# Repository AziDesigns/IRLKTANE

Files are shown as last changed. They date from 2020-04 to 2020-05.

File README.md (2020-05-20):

# IRLKTANE
A real life (but not really real) version of the game Keep Talking and Nobody Explodes
Built for - Arduino

Inspired by one of my favorite games (KTaNE) and the realization that this could be made into a physical version after seeing a reddit post by u/advicevice of the "maze" module I decided I had to build it myself.

The goal is not to make hot swappable modules but rather 1 of each module that works. 
Some modules are obviously not as realistic (ex. wire sequences) if I want it to be EXACTLY like the game but I am willing to make small adjustments to make it follow the same original game rules. 

*I do not plan to make any moded modules at this time but may in the future if all other modules are completed and optimized.*

The game is played with a minimum of 2 players, with one player as the "Defuser" and the remaining player(s) as the "Experts" reading the official bomb defusal manual from KTaNE VERSION 1 - VERIFICATION CODE #241 ONLY. I am not going to cover all game rules here, just go look at the manual on their site.

Currently it is being built with fixed variables but the goal will be once all modules are working as intended, you can create/ customize the difficulty by turning specific modules on/off as well as adjusting things like # of strikes (3 by default) or starting time (7 minutes by default).
*Fixed Variables include things like ports, batteries, & lit indicators.*

There will NOT be any 3d models released as I plan to make this out of wood, sheet metal, and plexiglass cutouts to hide/show the batteries, ports, etc.

#### Table of Contents
1. Getting Started w/ Software
- 1.1. Needed Libraries/ Files
- 1.2. Installation
2. Components
3. Modules
4. Built With
5. Authors
6. Credits

#### 1. Getting Started
These instructions will get you a copy of the project up and running.

#### 1.1 Prerequisites
In order for the code to work, you will need the following libraries:

- SevenSegmentTM1637 - [link](https://github.com/bremme/arduino-tm1637) 
- LedControl - [link](https://github.com/wayoda/LedControl)
- [REMOVED / NO LONGER NEEDED]~~LiquidCrystal~~ - [link](https://www.arduinolibraries.info/libraries/liquid-crystal)
- LiquidCrystal_I2C - [link](https://www.arduinolibraries.info/libraries/liquid-crystal-i2-c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)
- The files in this repository

#### 1.2 Installation
    1 - Download the .zip files for the libraries
    2 - Open Arduino IDE
    3 - Click Sketch -> Include Library -> Add .ZIP Library
    4 - Select the library zip file you downloaded
    5 - Repeat steps 3 and 4 for each library
    6 - Download the files in this repository and put all of them in the Arduino folder (sub-folder name must match .ino file name)

A Fritzing scheme has been added to this repository with instructions to build the circuit. It is a *WIP*, and as each module gets tested I will continue to update the pin mapping. (For example, right now each LED goes directly to the arduino, in the future they will all be run from a MAX7219 to reduce pin usage)

Next, connect the Arduino board to your computer and load the program to the board.

#### 2. Components (List Subject to Change) - will be updated upon completion of final build as it continues to change.
    1 - Arduino MEGA 2560 R3
    2 - Neopixel Stick
    1 - Red 7-segment clock display
    3 - 7 Segment Display (2-Digit)
    1 - Adafruit NeoPixel NeoMatrix 8x8 - 64 RGB LED Pixel Matrix
    4 - MAX7219 (DRIVES DISPLAYS AND LED MATRIX)
    1 - CUSTOM LED Matrix PCB or Make your own DIY on perfboard
    27 - Green LED
    2 - Yellow LED
    1 - 7 Segment Display (Single Digit)
    2 - 7 Segment Display - 20mm (4 Digit)
    1 - Red Square LED Button
    1 - Blue Square LED Button
    1 - Yellow Square LED Button
    1 - Green Square LED Button
    1 - 5-way Navigation switch
    1 - Snap-Action Standard Micro Switch with Lever
    30 - Mini Pushbutton Switch
    1 - RGB Button
    3 - LCD Display 16x2 I2C
    1 - LCD Display 20x4 I2C
    1 - large fake capacitor //for the needy module aesthetics
    Many Resistors, Capacitors, and Jumpers

#### 3. Modules

| Module Type  | Module Name | Sketched | Coded | Made |
| --- | --- |:---:|:---:|:---:|
| Normal | Button |:heavy_check_mark:|:heavy_check_mark:|:heavy_check_mark:|
| Needy | Capacitor Discharge |:heavy_check_mark:|:heavy_check_mark:|:heavy_check_mark:|
| Needy | Knob |:heavy_check_mark:|:heavy_check_mark:|:heavy_check_mark:|
| Normal | Maze |:heavy_check_mark:|:heavy_check_mark:|:heavy_check_mark:|
| Normal | Memory |:heavy_check_mark:|:heavy_check_mark:| |
| Normal | Morse |:heavy_check_mark:|:heavy_check_mark:|:heavy_check_mark:|
| Normal | Password |:heavy_check_mark:|:heavy_check_mark:| |
| Normal | Simon Says |:heavy_check_mark:|:heavy_check_mark:|:heavy_check_mark:|
| Needy | Venting Gas |:heavy_check_mark:| | |
| Normal | Who's On First |:heavy_check_mark:|:heavy_check_mark:|:heavy_check_mark:|
| Widget | Buzzer |:heavy_check_mark:|:heavy_check_mark:|:heavy_check_mark:|
| Widget | Timer |:heavy_check_mark:|:heavy_check_mark:|:heavy_check_mark:|
| Widget | Strikes |:heavy_check_mark:|:heavy_check_mark:|:heavy_check_mark:|
| Widget | Batteries |:heavy_check_mark:| | |
| Widget | Indicators |:heavy_check_mark:| | |
| Widget | Ports |:heavy_check_mark:| | |
| Normal | Complicated Wires | | | |
| Normal | Keypad (Symbols) | | | |
| Normal | Wire Sequence | | | |
| Normal | Wires | | | |

#### 4. Built With
[Arduino](https://www.arduino.cc/en/main/software) - The IDE used to code the modules logic.

[Fritzing](http://fritzing.org/home/) - The program used to create the components layout and wiring diagram.

#### 5. Authors
AziAssassin

#### 6. Credits
Thanks to calingeorgeadrian && ema1ih for setting the ground work for me to learn and get the basics of how they wrote their version of a select few of these modules.

Thanks to reddit u/advicevice for making me realize the potential this idea had to become a phyical game.

Last but not least: Keep Talking and Nobody Explodes - the [game](https://keeptalkinggame.com/) that inspired me in the first place.

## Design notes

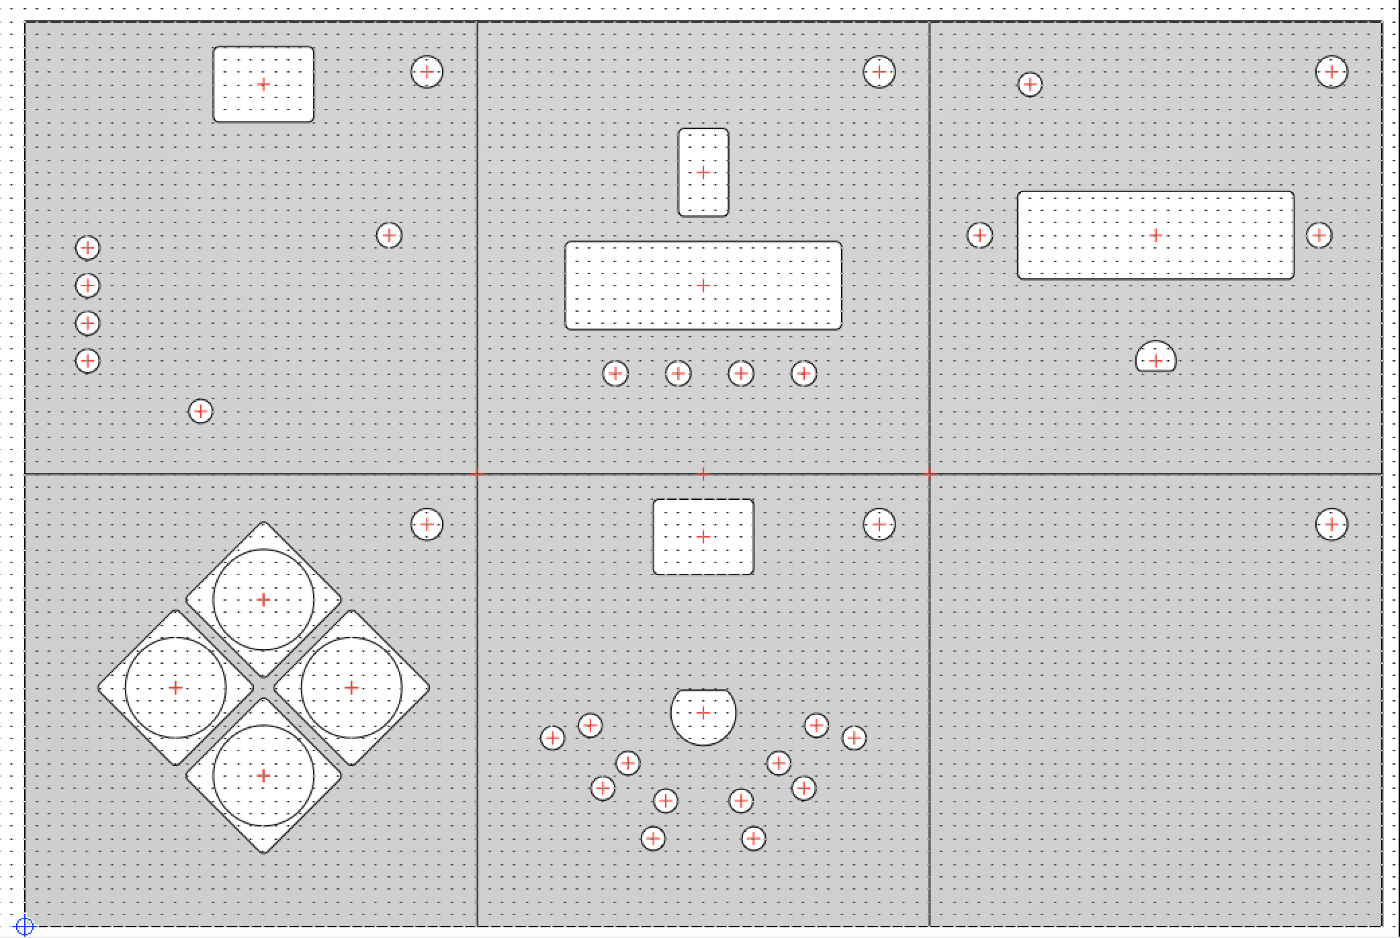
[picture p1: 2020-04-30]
PanelDesigns/rearPanelImageV1.png

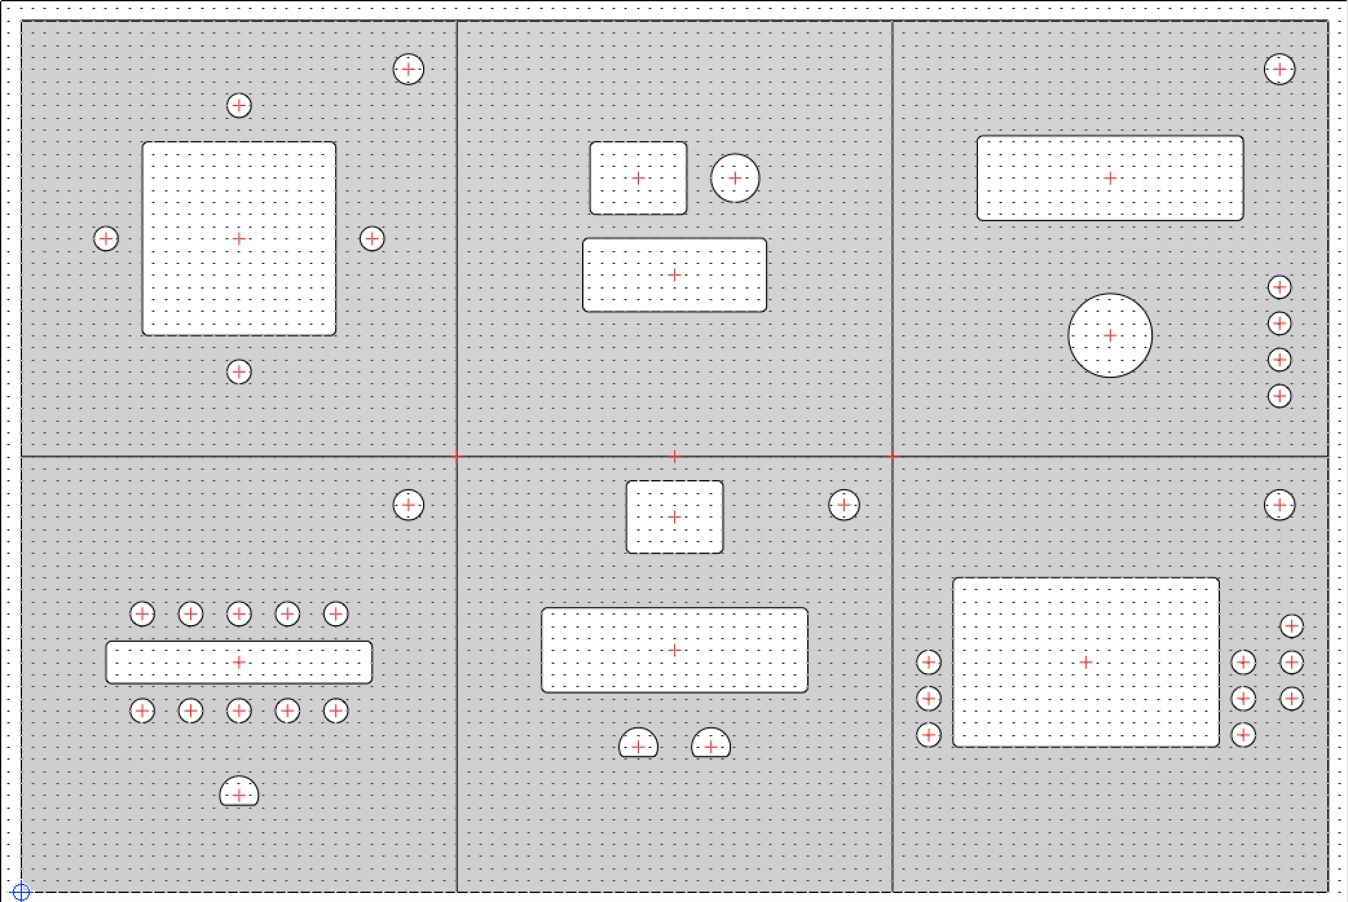
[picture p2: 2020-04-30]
PanelDesigns/frontPanelImagev1.png

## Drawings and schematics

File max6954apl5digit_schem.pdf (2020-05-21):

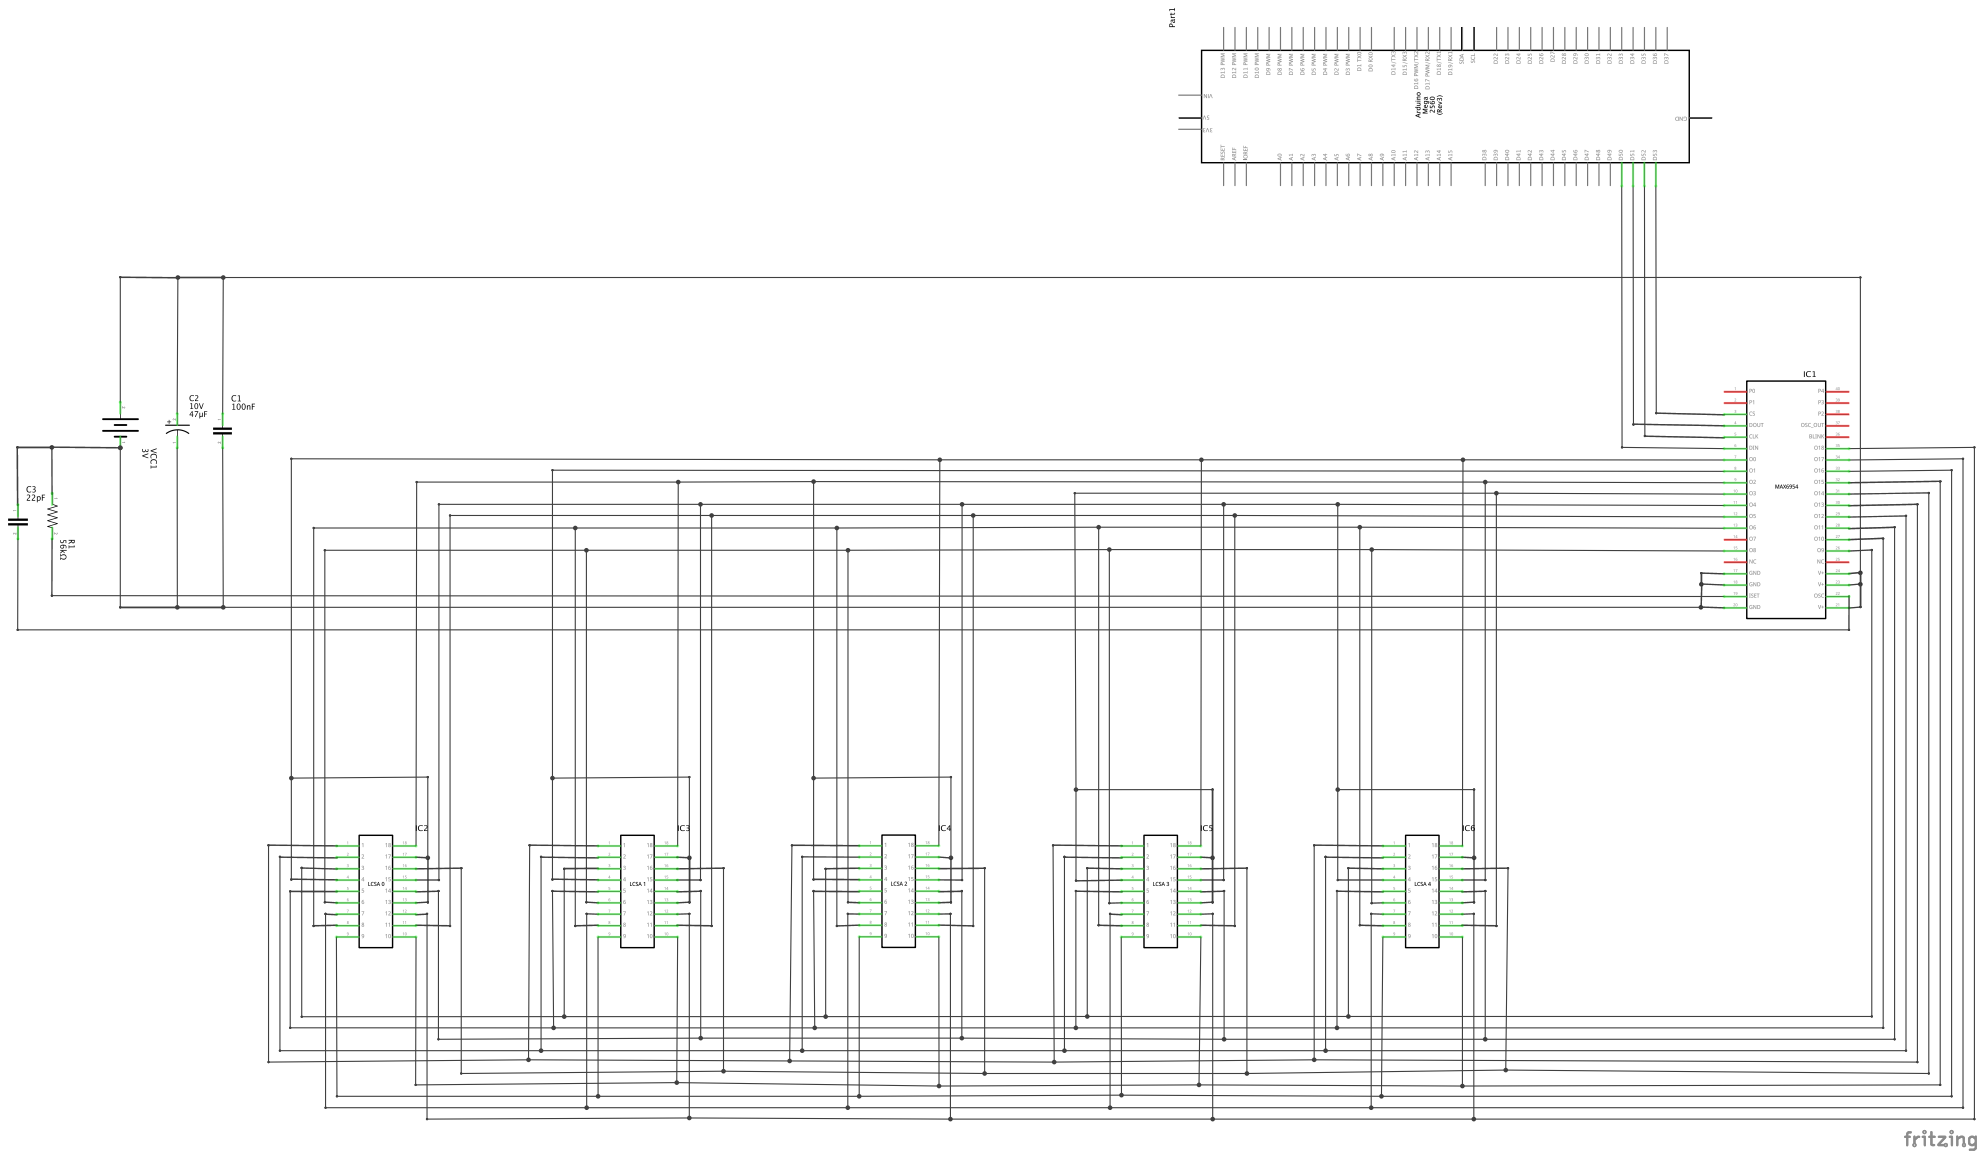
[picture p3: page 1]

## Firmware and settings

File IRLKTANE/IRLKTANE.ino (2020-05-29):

//THIS BOMB USES KTANE BOMB DEFUSAL MANUAL VERSION 1 VERIFICATION CODE #241 ONLY
/*
  KNOWN ISSUES:
  Module lights are staying on after bomb is defused. Only lights that should stay on are module complete green leds
*/
#include <LiquidCrystal_I2C.h>
#include <LedControl.h>
#include <SevenSegmentExtended.h>

#define BOMB_TIMER_MINUTES 7 // total bomb starting time min
#define BOMB_TIMER_SECONDS 0 // total bomb starting time sec

/*  LEVEL 0 = MINIMAL SERIAL PRINT
    LEVEL 1 = PER USER ACTION LOGGING & BOMB VALUES
    LEVEL 2 = PER FUNCTION CALL LOGGING
    LEVEL 3 = SAME AS L3 WITH loop, setup, morseDisplay, displayTime, and mazeOne FUNCTIONS INCLUDED
    MORE LEVELS IN THE FUTURE?
*/
#define DEBUG_LEVEL 2

bool defused = false, exploded = false, victorySong = false, isAnyModuleDefused = false; // is bomb defused or exploded default values false

#define PIN_MAX7219_LOAD 30 // MAX7219CNG  pin 9 STCP
#define PIN_MAX7219_CLOCK 31 // MAX7219CNG  pin 10 SHCP
#define PIN_MAX7219_DIN 32 // MAX7219CNG  pin 8 DS

#define DEBOUNCE_DELAY 50 // DELAY TO PREVENT DEBOUNCE ON SOME BUTTONS

// initialize the max7219 daisy chain used across other modules // LAST NUMBER IS THE MAX NUMBER OF MAX7219's in the chain
LedControl lc=LedControl(PIN_MAX7219_DIN,PIN_MAX7219_CLOCK,PIN_MAX7219_LOAD,3);

// for testing purposes and potential future (ability to select modules) feature these flags will determine which flags below should be included/ excuded by setting the value to true/false.
bool
buttonModuleIncluded = false,
dischargeModuleIncluded = false,
knobModuleIncluded = true,
mazeModuleIncluded = true,
memoryModuleIncluded = false,
morseModuleIncluded = false,
passwordModuleIncluded = false,
simonModuleIncluded = false,
ventingModuleIncluded = false,
whoModuleIncluded = false;

// on new bomb all modules start with default "is difused" state of False, set to true if you dont want to have to do the modules for testing
bool
buttonModuleDefused = false,
knobModuleStike = false,
mazeModuleDefused = false,
memoryModuleDefused = false,
morseModuleDefused = false,
passwordModuleDefused = false,
simonModuleDefused = false,
whoModuleDefused= false;

bool explodedFromStrikes = false; // is bomb exploded from strikes default value false
byte nrStrikes = 0; // number of strikes default starting is 0 (could be changed in future to allow only 1 strike, etc)

char serialCode[10];

void generateSerialCode() // function that generates the serial number for the bomb
{
  if (DEBUG_LEVEL >= 2) {
    Serial.println (__func__);
  }
  char alphanumeric[50] = {'A', 'B', 'C', 'D', 'E', 'F', 'G', 'H', 'I', 'J', 'K', 'L', 'M', 'N', 'O', 'P', 'Q', 'R', 'S', 'T', 'U', 'V', 'W', 'X', 'Y', 'Z', '1', '2', '3', '4', '5', '6', '7', '8', '9'};
  for ( byte i = 0; i < 7; i++)
    serialCode[i] = alphanumeric[random(0, 35)];
  Serial.println (serialCode);
}

unsigned int bitOut(void)
{
  static unsigned long firstTime=1, prev=0;
  unsigned long bit1=0, bit0=0, x=0, port=0, limit=99;
  if (firstTime)
  {
    firstTime=0;
    prev=analogRead(port);
  }
  while (limit--)
  {
    x=analogRead(port);
    bit1=(prev!=x?1:0);
    prev=x;
    x=analogRead(port);
    bit0=(prev!=x?1:0);
    prev=x;
    if (bit1!=bit0)
      break;
  }
  return bit1;
}

unsigned long seedOut(unsigned int noOfBits)
{
  // return value with 'noOfBits' random bits set
  unsigned long seed=0;
  for (int i=0;i<noOfBits;++i)
    seed = (seed<<1) | bitOut();
  return seed;
}

// list all modules/ header files that should be included
// ** buzzer.h and time.h must be at the top as they are called by other functions

#include "buzzer.h"
#include "time.h"
#include "morse.h" //higher in list so the max7219 chain will be loaded before other modules that need it
#include "indicator.h"
#include "batteries.h"
#include "needydisplays.h"
#include "button.h"
#include "discharge.h"
#include "knob.h"
#include "maze.h"
#include "memory.h"
#include "password.h"
#include "simon.h"
#include "venting.h"
#include "who.h"

void setup() // this section includes all setups for all modules to define INPUTS/OUTPUTS/DEFAULT VALUES/ ETC
{
  if (DEBUG_LEVEL >= 3) {
    Serial.println (__func__);
  }
  Serial.begin(9600);
// create 31 bit seed and show value, random results
  unsigned long seed=seedOut(31);
  randomSeed(seed);

  lcdButton.init();
  lcdButton.backlight();

  generateSerialCode();
  lcdButton.clear();
  lcdButton.setCursor(0, 1);
  lcdButton.print(F("Serial: "));
  lcdButton.print(serialCode);

  lc.shutdown(0,false);
  lc.shutdown(1,false);
  lc.shutdown(2,false);
  lc.setIntensity(0,10);
  lc.setIntensity(1,10);
  lc.setIntensity(2,10);
  lc.clearDisplay(0);
  lc.clearDisplay(1);
  lc.clearDisplay(2);
  
  timeSetup();
  buzzerSetup();
  
  if (buttonModuleIncluded==true) {
    buttonSetup();
  } else {
    buttonModuleDefused = true;  
  }
  if (dischargeModuleIncluded==true) {
    dischargeSetup();
  } else {  
  }
  if (knobModuleIncluded==true) {
    knobSetup();
  }
  if (mazeModuleIncluded==true) {
    mazeSetup();
  } else {
    mazeModuleDefused = true; 
  }
  if (memoryModuleIncluded==true) {
    memorySetup();
  } else {
    memoryModuleDefused = true; 
  }
  if (morseModuleIncluded==true) {
    morseSetup();
  } else {
    morseModuleDefused = true; 
  }
  if (passwordModuleIncluded==true) {
    passwordSetup();
  } else {
    passwordModuleDefused = true; 
  }
  if (simonModuleIncluded==true) {
    simonSetup();
  } else {
    simonModuleDefused = true;
  }
  if (ventingModuleIncluded==true) {
    ventingSetup();
  } else {
    lcdVent.init();
    lcdVent.off();
  }
  if (whoModuleIncluded==true) {
    whoSetup();
  } else {
    whoModuleDefused= true;
    lcdWho.init();
    lcdWho.off();
  }
}

void bombExploded() // what should each module do when exploded
{
  if (DEBUG_LEVEL >= 2) {
    Serial.println (__func__);
  }
  exploded = true;
  
  if (buttonModuleIncluded==true) {
    buttonModuleBoom();
  }
  if (dischargeModuleIncluded==true) {
    dischargeModuleBoom();
  }
  if (knobModuleIncluded==true) {
    knobModuleBoom();
  }
  if (mazeModuleIncluded==true) {
    mazeModuleBoom();
  }
  if (memoryModuleIncluded==true) {
    memoryModuleBoom();
  }
  if (morseModuleIncluded==true) {
    morseModuleBoom();
  }
  if (passwordModuleIncluded==true) {
    passwordModuleBoom();
  }
  if (simonModuleIncluded==true) {
    simonModuleBoom();
  }
  if (ventingModuleIncluded==true) {
    ventingModuleBoom();
  }
  if (whoModuleIncluded==true) {
    whoModuleBoom();
  }
  boomBuzzer();//needs to be last due to delays?
  timeModuleBoom();//needs to be last due to delays?
}

void addStrike() // function that adds a strike
{
  if (DEBUG_LEVEL >= 2) {
    Serial.println (__func__);
  }
  nrStrikes++;

  if (nrStrikes == 1) lc.setDigit(1,0,9,true); // use to set strike #1 on
  else if (nrStrikes == 2) lc.setDigit(1,1,9,true); // use to set strike #2 on
  else if (nrStrikes == 3) { // the maximum number of strikes is reached
    explodedFromStrikes = true;
    bombExploded();
  }
  strikeBuzzer();
}

void loop()
{
  if (DEBUG_LEVEL >= 3) {
    Serial.println (__func__);
  }

  timeLoop();

  if (!defused && !exploded) {
    
      if (buttonModuleIncluded==true) {
        buttonLoop();
      }
      if (dischargeModuleIncluded==true) {
        dischargeLoop();
      }
      if ((knobModuleIncluded==true) && (knobModuleStike==false)) {
        knobLoop();
      }
      if (mazeModuleIncluded==true) {
        mazeLoop();
      }
      if (memoryModuleIncluded==true) {
        memoryLoop();
      }
      if (morseModuleIncluded==true) {
        morseLoop();
      }
      if (passwordModuleIncluded==true) {
        passwordLoop();
      }
      if (simonModuleIncluded==true) {
        simonLoop();
      }
      if (ventingModuleIncluded==true) {
        ventingLoop();
      }
      if (whoModuleIncluded==true) {
        whoLoop();
      }
  }

  if (!exploded && (
        buttonModuleDefused &&
        mazeModuleDefused &&
        memoryModuleDefused &&
        morseModuleDefused &&
        passwordModuleDefused &&
        simonModuleDefused &&
        whoModuleDefused
      ))
  {
    if (victorySong==false) {
    defused = true;
    dischargeBombDefused();
    knobBombDefused();
    ventingBombDefused();
    victoryBuzzer();
    }
  }
}

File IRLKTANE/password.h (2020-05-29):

// On the Subject of Passwords
/*
  KNOWN ISSUES:
*/
#include "Adafruit_LEDBackpack.h"

#define PIN_PASSWORD_LED_FIN 2,4,3 // module complete led
#define PIN_PASSWORD_BUTTON_1 33 // letter 1 up
#define PIN_PASSWORD_BUTTON_2 34 // letter 2 up
#define PIN_PASSWORD_BUTTON_3 35 // letter 3 up
#define PIN_PASSWORD_BUTTON_4 36 // letter 4 up
#define PIN_PASSWORD_BUTTON_5 37 // letter 5 up
#define PIN_PASSWORD_BUTTON_6 38 // letter 1 down
#define PIN_PASSWORD_BUTTON_7 39 // letter 2 down
#define PIN_PASSWORD_BUTTON_8 40 // letter 3 down
#define PIN_PASSWORD_BUTTON_9 41 // letter 4 down
#define PIN_PASSWORD_BUTTON_10 42 // letter 5 down
#define PIN_PASSWORD_BUTTON_SUBMIT 43 // submit button

Adafruit_AlphaNum4 alpha5 = Adafruit_AlphaNum4();

unsigned long PWswitchMillis = 0;

byte passwordPos1UpState = 0; // current state of the 1st pos up button
byte passwordPos2UpState = 0; // current state of the 2nd pos up button
byte passwordPos3UpState = 0; // current state of the 3rd pos up button
byte passwordPos4UpState = 0; // current state of the 4th pos up button
byte passwordPos5UpState = 0; // current state of the 5th pos up button

byte passwordPos1DownState = 0; // current state of the 1st pos Down button
byte passwordPos2DownState = 0; // current state of the 2nd pos Down button
byte passwordPos3DownState = 0; // current state of the 3rd pos Down button
byte passwordPos4DownState = 0; // current state of the 4th pos Down button
byte passwordPos5DownState = 0; // current state of the 5th pos Down button

byte passwordSubmitState = 0; // current state of the submit button

byte lastPasswordPos1UpState = 0; // previous state of the 1st pos up button
byte lastPasswordPos2UpState = 0; // previous state of the 2nd pos up button
byte lastPasswordPos3UpState = 0; // previous state of the 3rd pos up button
byte lastPasswordPos4UpState = 0; // previous state of the 4th pos up button
byte lastPasswordPos5UpState = 0; // previous state of the 5th pos up button

byte lastPasswordPos1DownState = 0; // previous state of the 1st pos Down button
byte lastPasswordPos2DownState = 0; // previous state of the 2nd pos Down button
byte lastPasswordPos3DownState = 0; // previous state of the 3rd pos Down button
byte lastPasswordPos4DownState = 0; // previous state of the 4th pos Down button
byte lastPasswordPos5DownState = 0; // previous state of the 5th pos Down button

byte lastPasswordSubmitState = 0; // previous state of the submit button

char displayVals[5] = {0,0,0,0,0};

byte randomArray[6]{0,0,0,0,0,0};

char positionVals[5][6] = {
 {0,0,0,0,0,0},
 {0,0,0,0,0,0},
 {0,0,0,0,0,0},
 {0,0,0,0,0,0},
 {0,0,0,0,0,0}
};

byte currentPositionPos[] = {0,0,0,0,0};

char validWords[35][5] = {
  {'A','B','O','U','T'},
  {'A','F','T','E','R'},
  {'A','G','A','I','N'},
  {'B','E','L','O','W'},
  {'C','O','U','L','D'},
  {'E','V','E','R','Y'},
  {'F','I','R','S','T'},
  {'F','O','U','N','D'},
  {'G','R','E','A','T'},
  {'H','O','U','S','E'},
  {'L','A','R','G','E'},
  {'L','E','A','R','N'},
  {'N','E','V','E','R'},
  {'O','T','H','E','R'},
  {'P','L','A','C','E'},
  {'P','L','A','N','T'},
  {'P','O','I','N','T'},
  {'R','I','G','H','T'},
  {'S','M','A','L','L'},
  {'S','O','U','N','D'},
  {'S','P','E','L','L'},
  {'S','T','I','L','L'},
  {'S','T','U','D','Y'},
  {'T','H','E','I','R'},
  {'T','H','E','R','E'},
  {'T','H','E','S','E'},
  {'T','H','I','N','G'},
  {'T','H','I','N','K'},
  {'T','H','R','E','E'},
  {'W','A','T','E','R'},
  {'W','H','E','R','E'},
  {'W','H','I','C','H'},
  {'W','O','R','L','D'},
  {'W','O','U','L','D'},
  {'W','R','I','T','E'}
};

void setInitDisplayLetters(byte p) 
{
  if (DEBUG_LEVEL >= 2) {
    Serial.println (__func__);
  }
  byte randomLetter = random(0,6);
  displayVals[p] = positionVals[p][randomLetter];
  currentPositionPos[p] = randomLetter;
}

void updatePasswordDisplay()
{
  if (DEBUG_LEVEL >= 2) {
    Serial.println (__func__);
  }
  for(byte i = 0; i < 5; i++)
  {
    Serial.print(displayVals[i]);
    alpha5.writeDigitAscii(i, displayVals[i]);
    alpha5.writeDisplay();
  }
  Serial.println(F(""));
}

void setDisplayLetters(byte bp, bool pm)
{
  if (DEBUG_LEVEL >= 2) {
    Serial.println (__func__);
  }
  byte currentLetterPos = currentPositionPos[bp];
  byte nextLetterPos;
  if (pm==true) {
    if (currentLetterPos==5) {
      nextLetterPos = 0;
      currentPositionPos[bp] = 0;
    } else {
      nextLetterPos = currentLetterPos+1;
      currentPositionPos[bp] = currentPositionPos[bp]+1;
    }
  } else if (pm==false) {
    if (currentLetterPos==0) {
      nextLetterPos = 5;
      currentPositionPos[bp] = 5;
    } else {
      nextLetterPos = currentLetterPos-1;
      currentPositionPos[bp] = currentPositionPos[bp]-1;
    }
  }
  displayVals[bp] = positionVals[bp][nextLetterPos];
  updatePasswordDisplay();
}

void genCorrectLetters()
{
  if (DEBUG_LEVEL >= 2) {
    Serial.println (__func__);
  }
  byte randomWord = random(0,35);
  byte positionPopulated = 0;
  while (positionPopulated<5)
  {
    char letter = validWords[randomWord][positionPopulated];
    positionVals[positionPopulated][0] = letter;
    positionPopulated ++;
  }
}

void genRandLetters(byte p)
{
  if (DEBUG_LEVEL >= 2) {
    Serial.println (__func__);
  }
  
  for(byte i = 1; i<6; i++){
      byte value;
      boolean check = false;
  
      while(check == false){
          value = random(0, 26);
          check = true;
          for(byte j = 1; j<6; j++){
            if(value == randomArray[j]){
              check = false;
            } 
          }
          char valueLetter = value + 'A';
          if (valueLetter == positionVals[p][0]) {
            check = false;
          }
      }
      randomArray[i] = value;
      char letter = value + 'A';
      positionVals[p][i] = letter;
  }
}

void checkPWSubmission()
{
  if (DEBUG_LEVEL >= 2) {
    Serial.println (__func__);
  }
  if ((displayVals[0]==positionVals[0][0]) &&
     (displayVals[1]==positionVals[1][0]) &&
     (displayVals[2]==positionVals[2][0]) &&
     (displayVals[3]==positionVals[3][0]) &&
     (displayVals[4]==positionVals[4][0])) {
    Serial.println(F("PWmoduledefused"));
    lc.setLed(PIN_PASSWORD_LED_FIN,true);
    passwordModuleDefused = true;
    defusedModuleBuzzer();
    isAnyModuleDefused=true;
   } else {
      addStrike();
   }
}
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

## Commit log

2020-04-15 First Load of Modules & Primary Functions
    First Load of modules and main functionality like timer, buzzer, etc. New modules to come once tested.
    [IRLKTANE.ino, buzzer.h, discharge.h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]
2020-04-16 Adding button module first attempt
    Adding button module first attempt
2020-04-16 Added templates for reamining possible modules
    Addeded templates for remaining known to be possible in the real world without modification modules. Will add others to complete original game after all exisiting listed modules are working without error.
    [IRLKTANE.ino, button.h, buzzer.h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]
2020-04-16 Fixed Compiling and Setup Error
    Fixed Compiling and Setup Error
    [IRLKTANE.ino, knob.h, maze.h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]
2020-04-16 Fixed incorrect pin assigments
    Fixed duplicate pin assigments, some of these pin assigments dont even exist on this board and will need to be fixed in the future. For now I just wanted each to have a unique assigment.
    [discharge.h, memory.h, password.h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]
2020-04-16 More pin notes for future clarity
    password.h still contains some invalid pin assignments. Board is maxed out on pins. Need to find ways to reduce pin usage or to add 2nd board?
2020-04-19 WIP Morse Module (still broken)
    This is a (working module) as far as the buttons, display, and all parts of the flashing LED except the morseBlinkWord() function. Will come back to fix later.
    [morse.h]
2020-04-19 Fix a few things from help on arduino forum
    Thanks for the help all.
    [morse.h]
2020-04-20 Fixed Morse LED Broke any time button presses
    The delays were added back in which causes some issues with button presses but fixes the led issues with the morse code.
    [morse.h]
2020-04-20 Fixed lots of little things for Morse
    Fixed blink code with feedback from arduino forum member (gcjr).
    Added all arrays for each word
    I plan to update the code still further to use the blinkWithoutDelay style of delays so the buttons can be pressed at any time.
    [morse.h]
2020-04-23 MAJOR morse.h fixes & updates
    Found way to allow button presses at any point in LED Flashing sequence.
    Still need to fix submit button delay that is hard coded. Will do in a future update. Moving to focus on new module.
    [morse.h, password.h, simon.h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]
2020-04-23 Updated all Morse arrays for correct manual version
    Updated all Morse arrays for correct manual version 1 verification code 241
    [IRLKTANE.ino, morse.h]
2020-04-25 MAJOR UPDATES READ DESC
    Cleaned up all formatting.
    Major updates to maze.
    Major updates to debug options and serial print.
    Buzzer changes to pitches/ tones. (new pitches.h file added)
    Added "Known Issues:" section to each file.
    Morse Delay changes
    Morse Fixed Duplicate array[14] problem.
    Morse may have fixed lingering display after boom. Needs further verification.
    Morse updated delays to use variables.
    Added seconds countdown timer buzzer to time.h. turned off for testing (it gets annoying :) )
    And probably many other small updates.
    [IRLKTANE.ino, button.h, buzzer.h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]
2020-04-27 Update Readme to Track Modules
2020-04-27 Adding compatible manual as backup
    The official manaul on bombmanual.com is still compatible with this module. Adding a PDF copy here as a backup in case the version on that page becomes unavailible or changes for any reason.
2020-04-28 Adding Widgets / ReWriting Button
    Added batteries.h for default battery count and future building of battery display counter/ window.
    Added indicator.h for default indicators FRK/CAR and future building of lit indicators.
    ReWrote most of the main button loop for better tracking. (Need to add better comments and debugging options)
    Moved Pins on several modules for expanded buttons.
    Updated buzzer to count how many times it has played the victory / failure song as it is part of main loop and would otherwise play forever.
    Moved maze to use random maze layout.
    Morse fixed word shell that had a missing letter in the array.
    Simon Says adjusted pin definition to use variables not fixed values and u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
    [IRLKTANE.ino, button.h, buzzer.h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]
2020-04-29 Added Front & Rear Panel Design
    Designed a front and rear panel of the game that has cutouts for the LED mounts, buttons, maze matrix, lcd's, etc. These will be converted to a PDF for anyone to print out once I can confirm their ac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
2020-04-30 Panel Images & Morse/Memory Update
    Updated Front Panel design slightly and added images in .png format for you to view. (also moved for organization)
    Disabled maze for testing new RGB matrix. Will add back after testing.
    Morse now uses updated Max7219 thanks to help from Reddit user u/other_thoughts for helping fix my resistor issue :)
    [IRLKTANE.ino, memory.h, morse.h]
2020-04-30 Updated Known Issues & Comments
    Moved #include ledcontrol to main ino.
    Cleaned up lots of comments.
    Updated all morse buttons to have unique morse name to prevent overlap issues.
    Updated simon led pins/states to all be unique names to prevent overlap issues.
    [IRLKTANE.ino, button.h, buzzer.h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]
2020-05-02 Discharge & Knob Rewrite + Small Updates
    Wrote Discharge module logic and built it on breadboard using button & LED. Small changes still needed for countdown display and lever instead of knob but main logic is in place.
    Wrote Knob module logic and built it on breadboard. Small changes needed to fine to rotary switch and timer but main logic in place and working.
    Updated notes in Maze, Password to be accurate and reduce clutter.
    Wrote logic in time.h to handle counting down at 1.25 or 1.5 times the speed when 1 or 2 strikes respectively are incurred.
2020-05-02 Fixed Stike/Boom logic for Needy Modules
    Fixed Stike/Boom logic for Needy Modules
    [IRLKTANE.ino, discharge.h, knob.h]
2020-05-02 Added Ability To Select Active Module
    Added ability to select which modules are currently active using a bool for each module. You can set this manually today via the IRLKTANE.ino file. Some day I may have a panel/knobs for controling this on the bomb itself and that will control these values.
    Updated Maze & Memory to no longer have conflict on the LedControl names being set as lc. Now are named mazelc and memorylc.
    [IRLKTANE.ino, maze.h, memory.h]
2020-05-02 Fixed Serial Number Display
    Updated serial number display to populate regardless of if the button module is enabled or not.
    Fixed overlapping pin assignements on inactive/ WIP modules.
    [IRLKTANE.ino, button.h, password.h]
2020-05-04 Update Discharge & Strikes Display & WHO Pins
    Changed discharge to use a 2 digit 14 segment display connected in series to a max7219 along side the strikes counter. Had to customize the pinning to make it work without a differnt chip. Therefore custom counter was needed for what should display for each letter. (Could be made into an array of bits to shorten code)
    Fixed Who's on First pin assignments
    [IRLKTANE.ino, discharge.h, morse.h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]
2020-05-05 Remove Unused Vars, Fix Overlapping Pins & Add .fzz
    Removed several unused variables that are no longer relavant across several .h files.
    Anywhere there was a pin overlap I assigned a fake pin # above max 53 + A0-15. (Will reassign once LED's are consolidated to use fewer pins)
    Removed unneeded function from passwords that was redundant.
    Adding .fzz fritzing file that is still a WIP. Many pin assignments & wiring missing.
    Fixed Simon unique name issue with blinkingTime and called it simonBlinkingTime
    [IRLKTANEfritzing.fzz]
2020-05-06 Fixed Unneded Panel Cutouts
    Removed Module Complete LED from needy modules.
2020-05-07 Updated PIN names, Changed Knob Timer, Fixed Pin # for 2
    Updated PIN names to be consistent. Changed Knob Timer from 1 style display to another.
    Fixed Pin # for 2 modules that were swapped in error.
    [IRLKTANE.ino, button.h, discharge.h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]
2020-05-08 Renamed Pin on All Modules/ Rebuilt Buzzer
    Renamed Module Complete LED_GREEN to LED_FIN to prevent issues with simon says or other green specific led's
    Changed all of buzzer config to play actual songs. Need to still update songs that are played DURING gameplay to not use delay()
    [IRLKTANE.ino, button.h, buzzer.h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]
2020-05-08 Fixed 3 Buzzer for loops
    3 for loops in the buzzer were pointing at fixed lenghts instead of the defined "Notes" lengths like the others.
    [buzzer.h]
2020-05-08 Updated Buzzer Songs & Updated WHO
    Updated Buzzer songs to play actual music. Victory and Boom use Delay because it dosent matter as the game is over. All others use a version with no delay to play sounds.
    Moved init of lcdWho to also happen if the who module is not selected so it could be shut off when not in use.
    Changed lcd to lcdWho so it would have unique name.
    Removed unused constant from venting.h
    [IRLKTANE.ino, buzzer.h, venting.h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]
2020-05-14 Major Password ReWrite & Comments Cleanup
    Removed unneeded comments from buzzer, changed which module is being tested "password = true" and small changes to fritzing files.
    COMPLETE REWRITE of the password module. It fully functions using the Serial.print to see the display. An actual 5 digit 14 segment display will be wired up and printed to eventually.
    Will also likely need to find a way to reduce the number of buttons from 11 for this 1 module to a smaller number. Will figure out how later :)
    [IRLKTANEfritzing.fzz]
2020-05-14 Password Preveting Duplicates
    Updated Password to prevent duplicates in the random array of incorrect letters.
    Changed Password SerialPrint debug to happen at a level 1 instead of level 2
    [IRLKTANE.ino, password.h]
2020-05-14 Improved RandomSeed, FIXED More PW Stuff
    Fixed Password.h for loop to do what was intended instead of looping for j times it now just checks for the position its in.
    Removed unneeded Serial.print commands from testing
    Made randomSeed more random starting position by adding to IRLKTANE.ino new fuctions that create a better randomized starting point.
    [IRLKTANE.ino, button.h, memory.h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]
2020-05-20 Moved LED's to Matrix & Rebuilt Maze
    Moved all LED's to a custom PCB that acts as an 8X8 LED matrix but does not require all LED's to be in matrix layout. This change means NO LED's need to use a single pin. All LED's are now in sequence using the MAX7219's.
    Cleaned up BUZZER definition to be consistent with naming across all .h files.
    Now that more pins are free due to no LED's being needed directly on a pin I moved the Load Clock and DIN pins to a more suitable position.
    Moved all pin assignements for anything that was considered overlapping.
    Converted Maze from MAX7219 prebuilt red only matrix to an Adafruit NeoPixel NeoMatrix 8x8. This only uses 1 data pin and only needed a few minor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
    [IRLKTANE.ino, button.h, buzzer.h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]
2020-05-21 Temp Add Schematic For Post
2020-05-25 Password and pin updates + other
    Updated a few PIN assigments for testing.
    Removed unneeded MEMORY LATCH< CLOCK< DATA as it will all be displayed on MAX7219's that are already deffined in IRLKTANE.ino
    Will update memory display assigments once wired to max7219.
    Updated Password Arrays to use capital letters instead of lowercase in order to not have to translate for display purposes.
    Updated password to output to an alphanumeric 5 digits 14 segment display driven via I2C on 0X70.
    Updated front panel layout to be non rounded edges based on testing.
2020-05-26 Fixing Dimensions of Panels
    Fixed dimensions of all panels to include a buffer zone between modules and an edge buffer zone for screwing to the wood frame. Frame will have metal dividers as well to add depth/ texture once built.
2020-05-29 Clean Up comments/known issues text
    Cleaned up comments & known issues text to be accurate.
    Small adjustments to panel designs placements and some button changes etc. More to come as final parts arrive for wires, buttons, and lever for discharge.
    [IRLKTANE.ino, discharge.h, knob.h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]
